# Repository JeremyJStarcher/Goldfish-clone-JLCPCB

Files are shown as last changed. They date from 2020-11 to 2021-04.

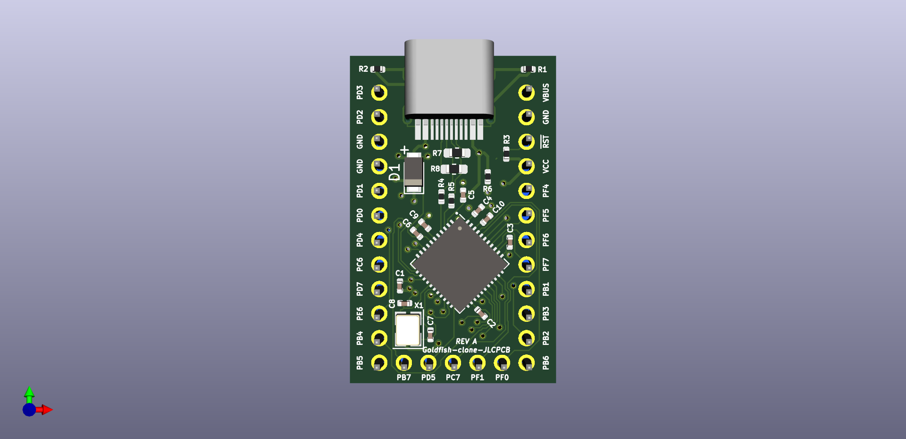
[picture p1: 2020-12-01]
doc/top.png

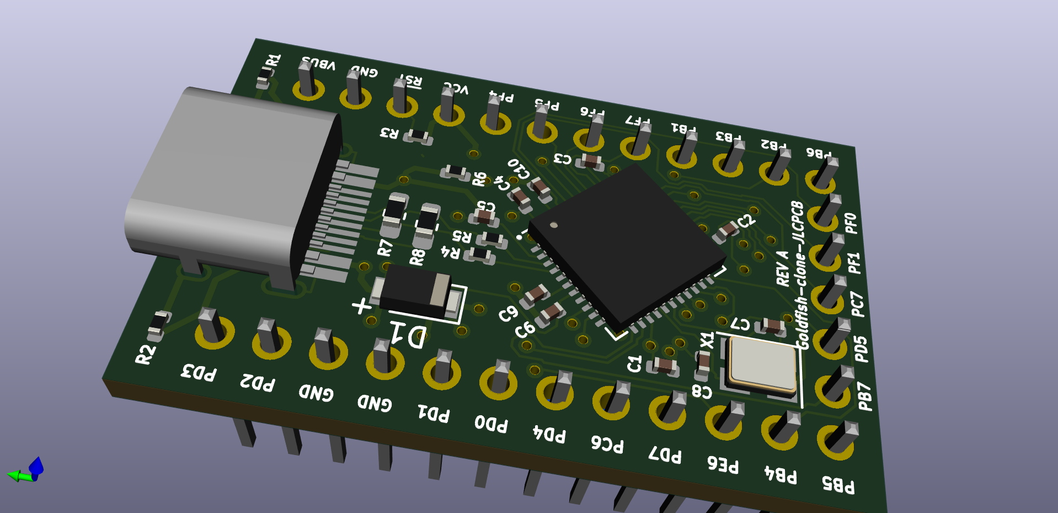
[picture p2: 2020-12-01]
doc/side.png

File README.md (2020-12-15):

# Goldfish-clone-JLCPCB

This board is a new layout for the original 
[Goldfish](https://github.com/staticintlucas/Goldfish)
by Lucas Jansen.

# REV A has several design issues that make it very difficult to attach the USB connector.

Do not use!

## Why?

This board was designed to be used with JLCPCB's SMD assembly service.  Because JLCPCB has very different requirements,
the board layout needed redesigned entirely.

## Important changes

* Four layer board with separate ground and power layers.  No additional charge, so why not?
* Board is wider to meet the minimum width requirements
* The board is longer to allow top-side labels all the way around
* Changed the USB connector to one that is more easily soldered by hand at the cost of making the board slightly thicker.
* Changed the crystal to match parts available.
* 0 Ohm resisters added to help USB data signal routing
* Additional USB Datapins removed.

## License Information
Released under the Creative Commons Attribution Share-Alike 4.0 License.  
https://creativecommons.org/licenses/by-sa/4.0/  

Original Arduino Mini Design by Team Arduino.  
Arduino Pro Mini Design by Spark Fun Electronics.  
Pro Micro Design by Spark Fun Electronics.  
Goldfish Design by Dr Derivative.  
JLCPCB assembly version by Jeremy J Starcher

## Revision History

* Rev A - Initial release.  On order - untested.

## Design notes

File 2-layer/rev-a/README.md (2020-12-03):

# 2 LAYER REV A

## This board was submitted to PCBWAY

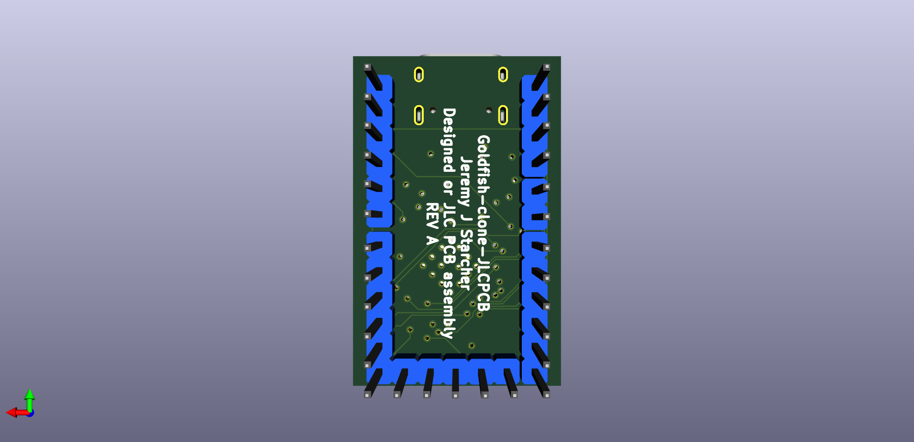
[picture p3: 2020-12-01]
doc/bottom.png

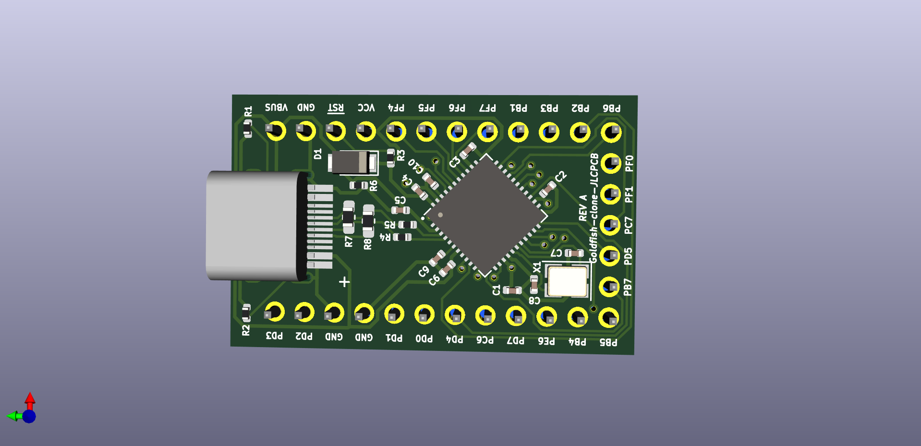
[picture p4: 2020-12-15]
2-layer/rev-a/top-render2.png

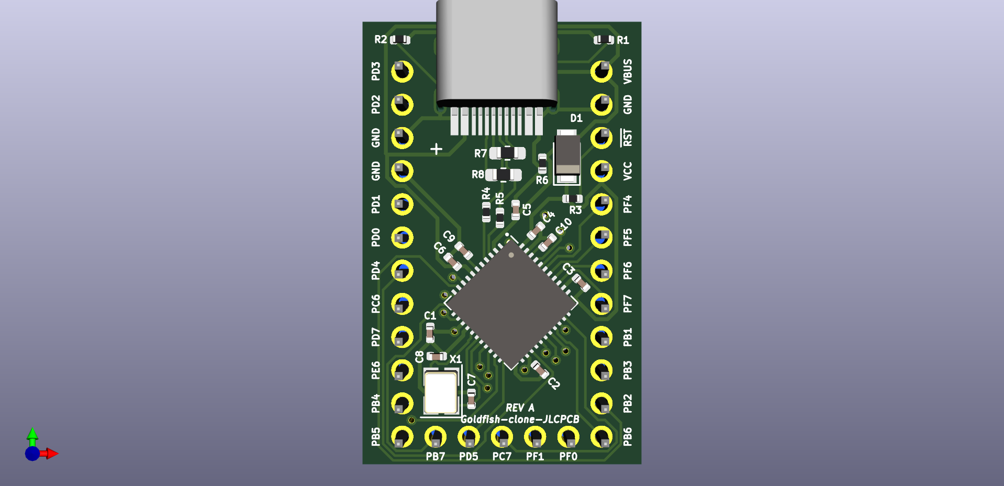
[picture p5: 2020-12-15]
2-layer/rev-a/top-render.png

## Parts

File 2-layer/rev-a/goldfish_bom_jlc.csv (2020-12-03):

Comment | Designator | Footprint | LCSC Part #
4u7 | C6 | C_0402_1005Metric | C23733
22p | C8,C7 | C_0402_1005Metric | C1555
1u | C9 | C_0402_1005Metric | C52923
0u1 | C10,C1,C2,C3,C4,C5 | C_0402_1005Metric | C1525
D_Schottky | D1 | D_PowerDI-123 | C8598
5k1 | R2,R1 | R_0402_1005Metric | C25905
10k | R3,R6 | R_0402_1005Metric | C25744
22 | R4,R5 | R_0402_1005Metric | C25092
0R | R7,R8 | R_0603_1608Metric_Pad1.05x0.95mm_HandSolder | C17168
ATmega32U4 | U1 | QFN-44-1EP_7x7mm_P0.5mm_EP5.2x5.2mm | C45874
16MHz | X1 | Crystal_SMD_SeikoEpson_TSX3225-4Pin_3.2x2.5mm | C13738

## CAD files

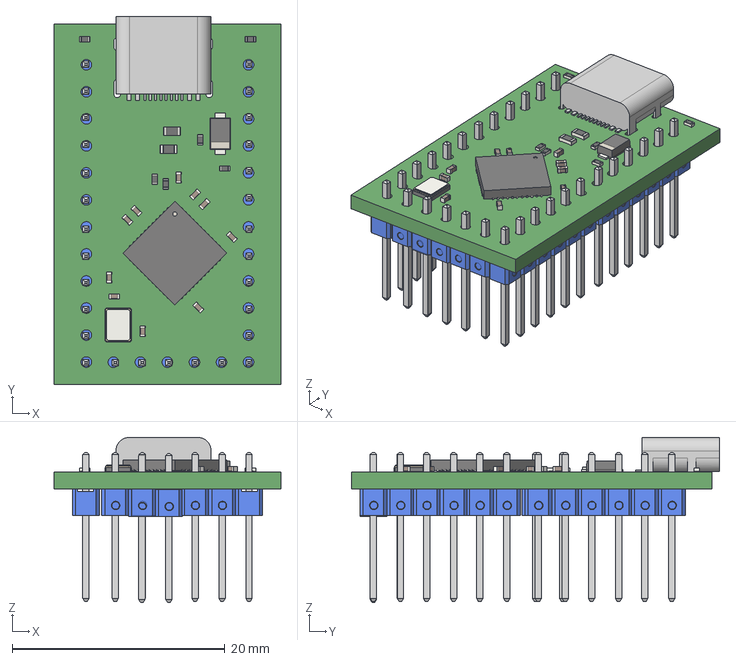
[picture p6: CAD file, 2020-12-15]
2-layer/goldfish/goldfish.step
21.3 x 34.6 x 15.5 mm

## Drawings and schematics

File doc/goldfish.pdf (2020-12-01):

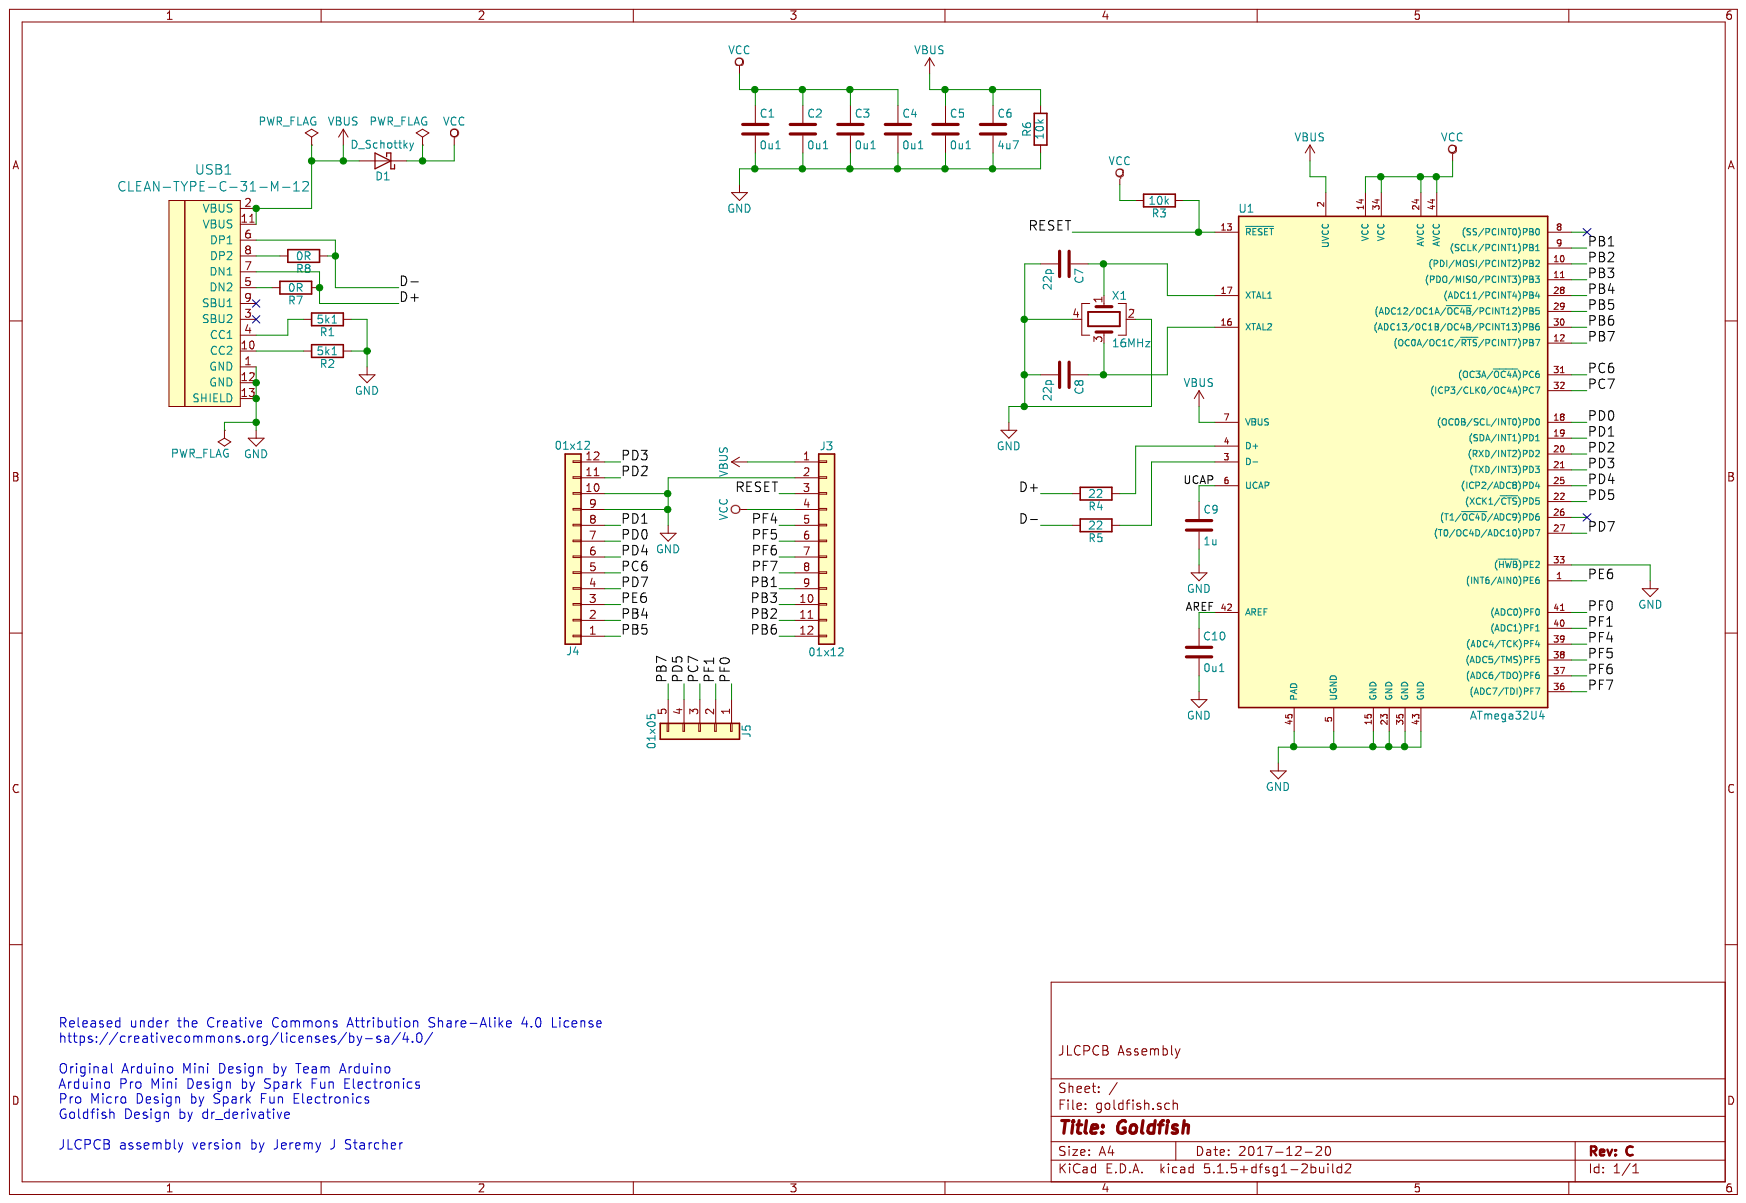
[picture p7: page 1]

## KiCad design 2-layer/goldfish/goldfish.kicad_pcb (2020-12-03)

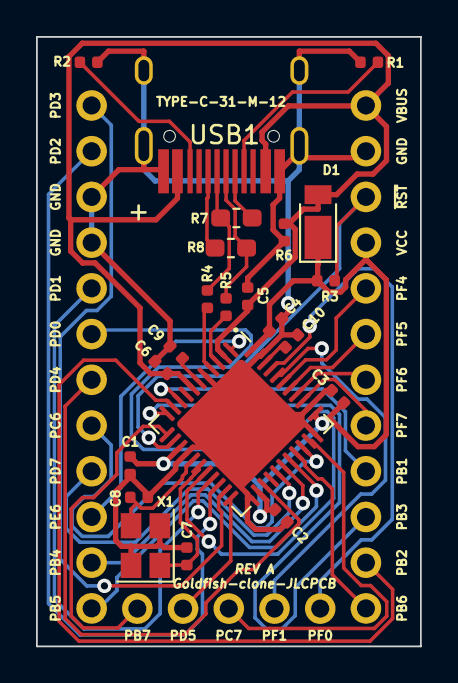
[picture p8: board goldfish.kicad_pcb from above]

Board: 2 copper layers, 21.3 x 33.9 mm, 25 parts (0 on the bottom side), 39 nets.

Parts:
C1, C2, C3, C4, C5, C10: 0u1; C_0402_1005Metric
C6: 4u7; C_0402_1005Metric
C7, C8: 22p; C_0402_1005Metric
C9: 1u; C_0402_1005Metric
D1: D_Schottky; D_PowerDI-123
J3, J4: 01x12; Pins12
J5: 01x05; Pins5
R1, R2: 5k1; R_0402_1005Metric
R3, R6: 10k; R_0402_1005Metric
R4, R5: 22; R_0402_1005Metric
R7, R8: 0R; R_0603_1608Metric_Pad1.05x0.95mm_HandSolder
U1: ATmega32U4; QFN-44-1EP_7x7mm_P0.5mm_EP5.2x5.2mm
USB1: TYPE-C-31-M-12; HRO-TYPE-C-31-M-12-HandSoldering
X1: 16MHz; Crystal_SMD_SeikoEpson_TSX3225-4Pin_3.2x2.5mm

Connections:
/AREF: C10.1, U1.42
/D+: R4.2, R7.1, USB1.7
/D-: R5.2, R8.1, USB1.6
/PB1: J3.9, U1.9
/PB2: J3.11, U1.10
/PB3: J3.10, U1.11
/PB4: J4.2, U1.28
/PB5: J4.1, U1.29
/PB6: J3.12, U1.30
/PB7: J5.5, U1.12
/PC6: J4.5, U1.31
/PC7: J5.3, U1.32
/PD0: J4.7, U1.18
/PD1: J4.8, U1.19
/PD2: J4.11, U1.20
/PD3: J4.12, U1.21
/PD4: J4.6, U1.25
/PD5: J5.4, U1.22
/PD7: J4.4, U1.27
/PE6: J4.3, U1.1
/PF0: J5.1, U1.41
/PF1: J5.2, U1.40
/PF4: J3.5, U1.39
/PF5: J3.6, U1.38
/PF6: J3.7, U1.37
/PF7: J3.8, U1.36
/RESET: J3.3, R3.1, U1.13
/UCAP: C9.1, U1.6
GND: C1.2, C2.2, C3.2, C4.2, C5.2, C6.2, C7.2, C8.2, C9.2, C10.2, J3.2, J4.9, J4.10, R1.1, R2.1, R6.1, U1.5, U1.15, U1.23, U1.33, U1.35, U1.43, U1.45, USB1.1, USB1.12, USB1.13, X1.2, X1.4
unnamed: C7.1, U1.17, X1.1
unnamed: C8.1, U1.16, X1.3
unnamed: R1.2, USB1.4
unnamed: R2.2, USB1.10
unnamed: R4.1, U1.4
unnamed: R5.1, U1.3
unnamed: R7.2, USB1.5
unnamed: R8.2, USB1.8
VBUS: C5.1, C6.1, D1.2, J3.1, R6.2, U1.2, U1.7, USB1.2, USB1.11
VCC: C1.1, C2.1, C3.1, C4.1, D1.1, J3.4, R3.2, U1.14, U1.24, U1.34, U1.44

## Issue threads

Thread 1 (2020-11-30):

PCB images

ellisgl, 2020-11-30:
May we have some PCB images (KiCAD / 3D view) in the docs?

JeremyJStarcher, 2020-11-30:
I'll put those in docs shortly ... I'm making some last minute tweaks before sending the board in.

JeremyJStarcher, 2020-12-01:
Pictures added...
I'm ready to upload all the files to JLCPCB but they are out of the ATMega32u4's in that footprint. :(

Closed 2020-12-01.

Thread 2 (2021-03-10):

Curious about issues with Rev A

vladkvit, 2021-03-10:
I'm curious about the issues you ran into with Rev A & USB-C mounting.

Context - I'm designing a rev 2 of a custom keyboard PCB. One of the things I'm thinking about is ditching a microcontroller and integrating AVR & USB-C natively on the PCB. I'm looking at reference Pro Micro clones to get a feel for the components & USB-C mounting.

piit79, 2021-04-11:
I'd also like to know what the issues are and if you made any progress fixing them. I'd love to get a bunch of these assembled by JLCPCB.

Thanks a lot for your efforts!

JeremyJStarcher, 2021-04-12:
Truthfully, I forget the issues I had with the Rev A board now --

Been too long since I've looked at it.

For the latest board, I've not been able to solder on the USB-C connector, even though I have one that is [in theory] capable of hand soldering.

I figure this is mostly because I am just a horrible klutz.

I just uploaded my Revision 'B' of the board -- which allows for both the USB-C port and a breakout board for the USB Micro connector.

My life got hectic at work and I'll be honest, I never got around to ordering this board, but working on it was part of my goal once life settled down a little.

I can't find an USB-C breakout board, as much as I'd love to have one.

https://www.banggood.com/10pcs-Micro-USB-To-Dip-Female-Socket-B-Type-Microphone-5P-Patch-To-Dip-With-Soldering-Adapter-Board-p-1165563.html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

moritz1000, 2021-04-12:
@JeremyJStarcher

> I can't find an USB-C breakout board, as much as I'd love to have one.

Something like this?

https://www.adafruit.com/product/4090

https://www.sparkfun.com/products/15100

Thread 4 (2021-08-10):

Usb C not included in bom file

AXRAY23, 2021-08-10:
Hi! I'm lookig to modify this design a bit then get it printed, but while i was looking at the reference cpl and bom files i noticed that the usb c port is not included in the bom one.

What's the reason for this? Is there a smd-soldering limitation from jlcpcb? Or is it simply designed to be hand soldered?

If there's no limitation i see they have the exact TYPE-C-31-M-12 in stock so i believe just adding it to the bom file with the required attributes should be enough.

JeremyJStarcher, 2021-08-11:
The last time I asked them to assemble that they didn't, but they are known
to sometimes miss the USB port.

I remember I was tempted to swap that out for a USBC breakout board... but
if they'll attach that port the GREAT...

I find hand-soldering it -- difficult, even the one meant for that.

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

AXRAY23, 2021-08-11:
Alright, got it. In that case I'll send it to get  assembled with the usb port and I'll update after the boards come to see how it goes.

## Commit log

2020-11-26 Init commit
    [goldfish.kicad_pcb, goldfish.sch]
2020-11-29 Total board redesign
    [full-route.kicad_pcb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]
2020-11-30 Silk Screen layers cleaned up and labels added.
    [goldfish.kicad_pcb]
2020-12-01 Added header pins to 3d model
    [goldfish.kicad_pcb, goldfish.sch]
2020-12-03 Final version of REV A as submitted.
    [goldfish_bom_jlc.csv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]
2020-12-03 Cleanup after submitting rev-a
    [goldfish-B_Cu.gbr, goldfish-B_Mask.gbr, goldfish-B_Paste.gbr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]
2020-12-03 2Layer board - Rev A - not as comfortable with this.
    [goldfish_bom_jlc.csv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]
2020-12-03 2Layer board - Rev A
    [full-route.kicad_pcb, goldfish.kicad_pcb, goldfish.sch]
2020-12-15 Rev A updated. Don't use.
    [goldfish.step]
2020-12-15 Removed junk files
    [full-route.kicad_pcb]
2021-04-12 Added the option for a USB-micro breakboard board on the USB as well.
    [goldfish.kicad_pcb]
